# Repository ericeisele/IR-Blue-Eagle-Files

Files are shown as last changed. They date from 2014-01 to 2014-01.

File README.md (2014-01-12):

IR-Blue-Eagle-Files
===================

IR-Blue Thermal Imaging Smartphone Accessory
<p>
This fork of the IR Blue hardware design (originally by RHWorkshop) will miniaturize the smartphone accessory, while adding the following features:
<ul>
<li>-Rechargable 180mAh Li-poly battery</li>
<li>-Micro USB charging port</li>
<li>-Built in charge management and low battery disconnect to prevent deep discharge of the battery</li>
<li>-Highly efficient (>90%) voltage regulation for enhanced battery life</li>
<li>-All SMT assembly</li>
<li>-3D printable enclosures that snap onto iPhone 5</li>
<li>-3D templates to customize enclosure for specific phone models</li>
</ul>

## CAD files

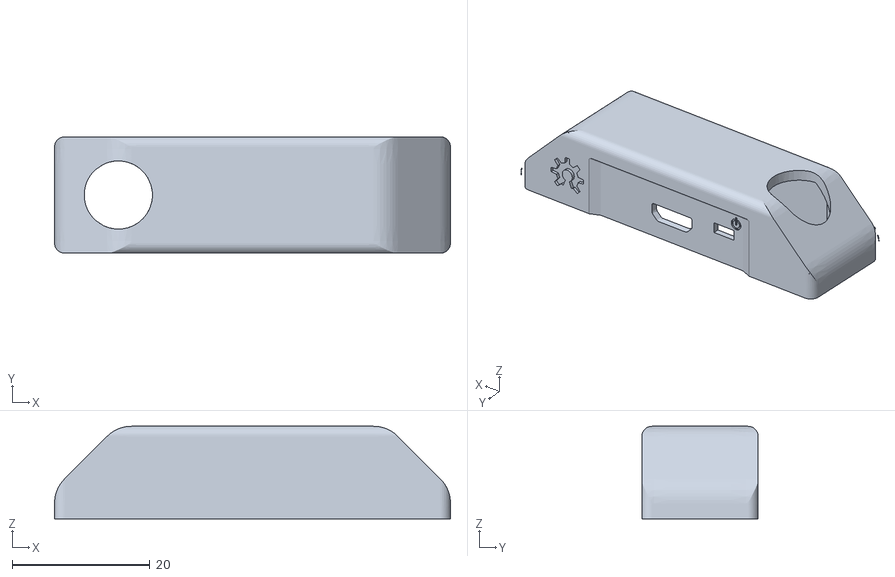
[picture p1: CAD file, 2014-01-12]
IR-Blue BT4/formlabs test.stl
57.6 x 16.9 x 13.5

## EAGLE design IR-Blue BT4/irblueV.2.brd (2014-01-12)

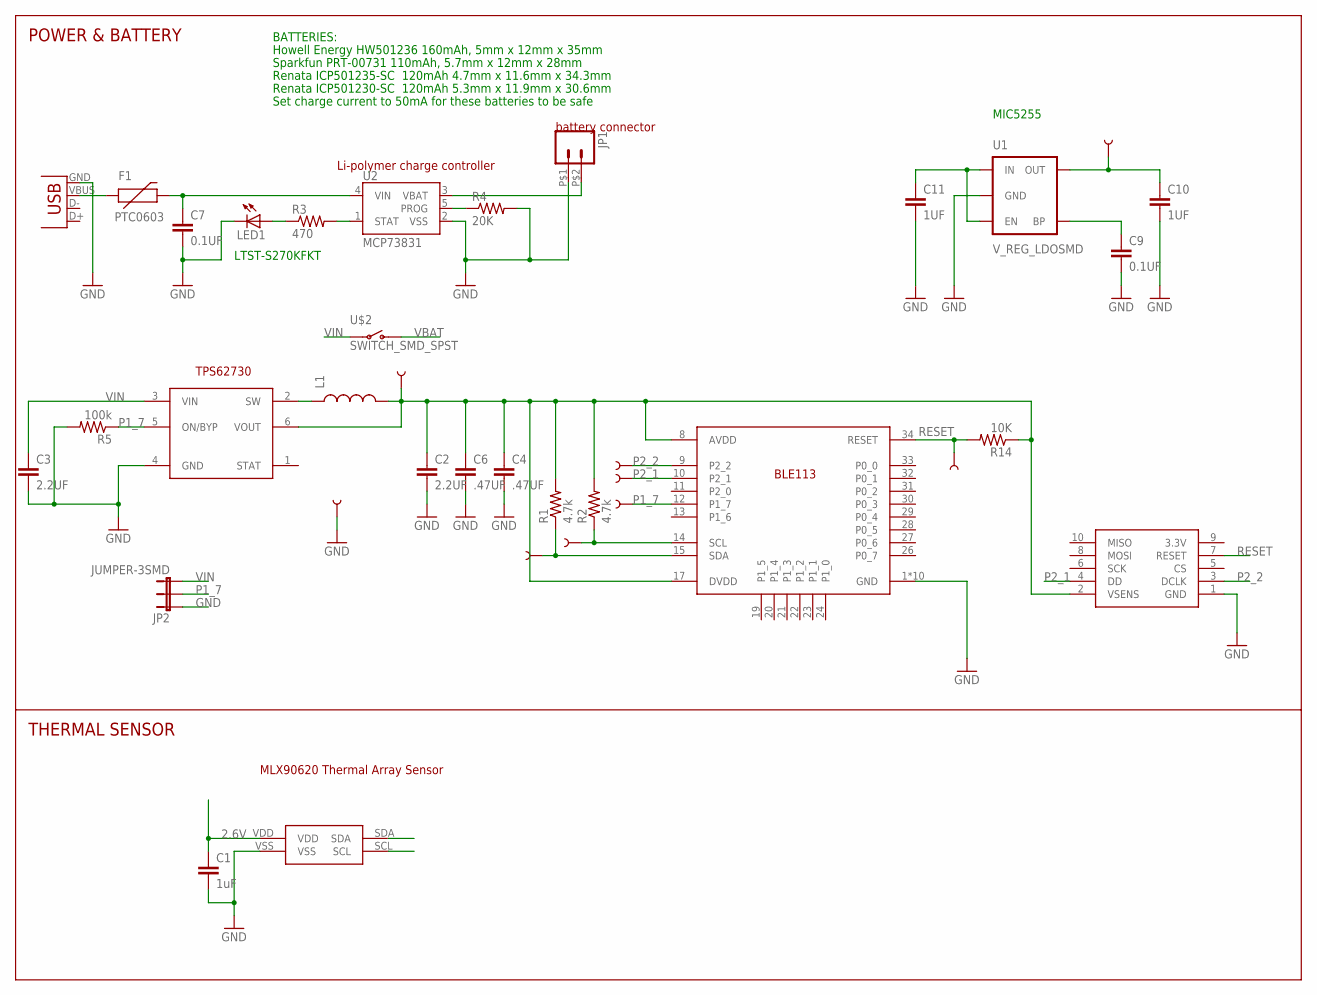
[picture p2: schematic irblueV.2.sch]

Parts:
C1: 1uF; 0402-CAP
C2, C3: 2.2UF; 0603-CAP
C4, C6: .47UF; 0402-CAP
C7, C9: 0.1UF; 0402-CAP
C10, C11: 1UF; 0402-CAP
F1: PTC0603; 0603
JP1: M02WIRE; 1X02_1-WIRE
JP2: JUMPER-3SMD; SJ_3
L1: INDUCTOR0805; 0805
LED1: LED0603; LED-0603
R1, R2: 4.7k; 0402-RES
R3: 470; 0402-RES
R4: 20K; 0402-RES
R5: 100k; 0402-RES
R14: 10K; 0402-RES
S1: MLX90620
TP1, TP2, TP3, TP4, TP5, TP6, TP7, TP8, TP9: TEST-POINT3X5; PAD.03X.05
U1: V_REG_LDOSMD; SOT23-5
U2: MCP73831; SOT23-5
U$1: TPS62730; SON-6
U$2: SWITCH_SMD_SPST; SWITCH-SPDT-SMD
U$5: BLE113
U$8: TAG_CONNECT_CC_DEBUGGER; TC2030-MCP-NL
X1: USB-MICROB

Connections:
2.6V: C1.1, C10.1, S1.VDD, TP9.P$1, U1.5 (OUT)
GND: C1.2, C2.2, C3.2, C4.2, C6.2, C7.2, C9.2, C10.2, C11.2, JP1.P$1 (1), JP2.1, LED1.C, R4.2, R5.2, S1.VSS, TP8.P$1, U1.2 (GND), U2.2 (VSS), U$1.4 (GND), U$5.1 (GND), U$5.2 (GND), U$5.3 (GND), U$5.4 (GND), U$5.5 (GND), U$5.6 (GND), U$5.7 (GND), U$5.18 (GND), U$5.25 (GND), U$5.36 (GND), U$8.1 (GND), X1.GND
unnamed: F1.1, X1.VBUS
unnamed: L1.1, U$1.2 (SW)
unnamed: R4.1, U2.5 (PROG)
unnamed: C7.1, F1.2, U2.4 (VIN)
unnamed: R3.2, U2.1 (STAT)
unnamed: LED1.A, R3.1
unnamed: C9.1, U1.4 (BP)
P1_7: JP2.2, R5.1, TP3.P$1, U$1.5 (ON/BYP), U$5.12 (P1_7)
P2_1: TP2.P$1, U$5.10 (P2_1), U$8.4 (DD)
P2_2: TP1.P$1, U$5.9 (P2_2), U$8.3 (DCLK)
RESET: R14.2, TP4.P$1, U$5.34 (RESET), U$8.7 (RESET)
SCL: R2.1, S1.SCL, TP5.P$1, U$5.14 (SCL)
SDA: R1.1, S1.SDA, TP6.P$1, U$5.15 (SDA)
VBAT: JP1.P$2 (2), U2.3 (VBAT), U$2.1 (O)
VIN: C3.1, C11.1, JP2.3, U1.1 (IN), U1.3 (EN), U$1.3 (VIN), U$2.2
VREG: C2.1, C4.1, C6.1, L1.2, R1.2, R2.2, R14.1, TP7.P$1, U$1.6 (VOUT), U$5.8 (AVDD), U$5.17 (DVDD), U$8.2 (VSENS)

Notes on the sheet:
BATTERIES:
Howell Energy HW501236 160mAh, 5mm x 12mm x 35mm
Sparkfun PRT-00731 110mAh, 5.7mm x 12mm x 28mm
Renata ICP501230-SC 120mAh 5.3mm x 11.9mm x 30.6mm
POWER & BATTERY
THERMAL SENSOR
Li-polymer charge controller
battery connector
MLX90620 Thermal Array Sensor
Renata ICP501235-SC 120mAh 4.7mm x 11.6mm x 34.3mm
Set charge current to 50mA for these batteries to be safe
LTST-S270KFKT
MIC5255

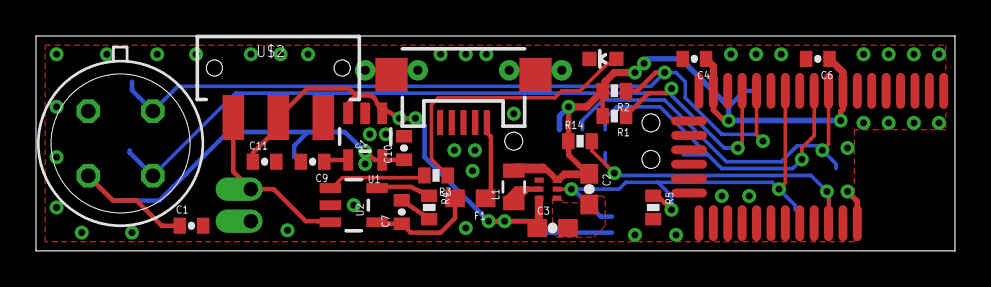
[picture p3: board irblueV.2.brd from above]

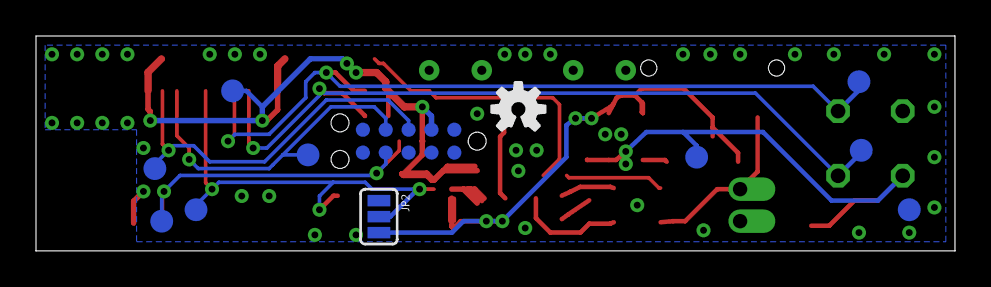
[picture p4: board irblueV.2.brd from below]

Board: 2 copper layers, 51.1 x 11.9 mm, 38 parts (12 on the bottom side), 18 nets.

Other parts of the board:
U$4: OSHW-LOGO-S

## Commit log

2014-01-12 Initial commit of redesigned IRBlue
    Redesigned the IRBlue smartphone thermal imaging accessory to include
    the new Texas Instruments CC2541 low energy Bluetooth chip, battery
    charging, efficient stepdown conversion with the TI TPS62730, and a 3D
    printed enclosure
    [formlabs test.stl, irblueV.2.brd, irblueV.2.sch]
2014-01-12 Cleaned up old files
    [IR-Blue BT2 PCB.brd, IR-Blue BT2 PCB.sch, IR-Blue BT4 PCB.brd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]

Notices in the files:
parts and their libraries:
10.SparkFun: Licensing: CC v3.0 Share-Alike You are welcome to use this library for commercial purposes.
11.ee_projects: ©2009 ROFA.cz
